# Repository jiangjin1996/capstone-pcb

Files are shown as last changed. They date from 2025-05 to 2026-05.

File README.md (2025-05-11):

# Analog Circuit Reliability for Low Earth Orbit Space Applications

In collaboration with the University of Saskatchewan, we are contributing a payload board
for the CubeSats Initiative in Canada for STEM (CUBICS). A CubeSat is a low cost, small
and approachable design for students “to engage in an end-to-end space mission
adapted to their needs and their level of comfort, expertise and readiness” (asc-csa.
gc.ca). Our payload studies the effects of space radiation on commonly used surface
mount analog Integrated Circuits (IC’s) in Low Earth Orbit (LEO). We compare different
shielding to see which provides a better effectiveness to weight ratio.

poster

## Software

Available [here](https://github.com/kaitallaoua/capstone-cubeide)

## Setup

This project used KiCad `Version: 7.0.11-7.0.11~ubuntu22.04.1, release build` and a mix of windows builds.
Download KiCad [here](https://www.kicad.org/download/). KiCad 8 likely does work and I recommend you use it.

## Workflow

TBD (remove this once done): Someone needs to fork this repo to make further contributions to the project. Using an organization is best, I think UofS space team has one, maybe Regina team should make one? Regardless I will not be reviewing and accepting PR's to this repo.

Because using git for KiCad is like tracking binary files, I recommend to NOT rely on git handling merge conflicts. Avoid them entirely by letting only one person make changes on one branch at a time, make a PR, approve and merge and repeat and pass the baton to someone else to make changes.

## TODO

- Get I2C working (unlikely any KiCad changes)
- Get sinewave generation working 
- Add Voltage regulator
- Triple check we fit in PC104, on RADSAT-SK1 printout we dont fit in all holes, also supposed to be some notches?
- Optional: Use solder-attched external non volatile storage such as FLASH, EEPROM (or solder/glue micro sd down??)

The most substantial changes the sinwave generation. This task was assigned to Evan. Ultimately we could not get it working, thus I recommend to use a PWM wave gen from the mcu, likely add pre-amplification + current buffering, and pass it to a sharp drop off filter. The filter could be a dedicated one (probably better) or an op-amp driven one (butterworth?, wont have as good drop off without many stages).

UofRobotics is also making a PCB for their robot whose base is forked from this project, they may be a good reference for questions or idea sharing.

## Manufacturing

We used JLCPCB for `REV A` and `REV B` with great results. We also have nearly all parts ready for another revision. AT LEAST ONE MORE REVISION IS NEEDED SINCE THE FOLLOWING WERE FIXED AFTER `REV B`:

- IC1 footprint solder mask was incorrectly removed
- Micro SD card holder was facing the wrong way

Our manufacturing procedure was as follows:

Order from JLC (1 week delivery), Order from Mouser/Digikey (2-4 day delivery) -> Have all parts -> Go to ED435, use microscope, have one person assist finding parts, one pick+place, apply solder paste (min 4-5 hours)-> place in oven -> done

I recommend to use the parts list available from JLCPCB or PCBWay to assemble as much of the board for you as possible, it saves alot of time but honestly building it by hand it also not that bad. Either is fine.

JLC ordering tips:
1. Search for JLC production toolkit to generate the BOM, part placement file.
2. Generate the gerber files with time stamps in the folder name to avoid confusion (only gerber is a really bad name)
3. and do not forget to generate the drill file and put it into the gerber folder(you don't need the toolkit for this)
4. You can hand pick components on JLC if the system cannot find them automatically
5. Double check the 3d model pops up after the components are selected because sometimes the auto selected parts can be the wrong ones
6. Ask for boarding cleaning on the first page of ordering
7. Select add paste for unpopulated pad & step stencil opening for easier installation in case JLC doesn't have the components? (Not sure about this but we will see)
8. These might apply to other manufacturers as well

## Resources

[KiCad 6 STM32 PCB Design Full Tutorial - Phil's Lab #65](https://www.youtube.com/watch?v=aVUqaB0IMh4)

[PCB Design Final Touches (Tips & Checklist) - Phil's Lab #131](https://www.youtube.com/watch?v=g4m91gv-4oQ)

## Front PCB

front_pcb

## Back PCB

back_pcb

## Front Copper Layer

front_cu

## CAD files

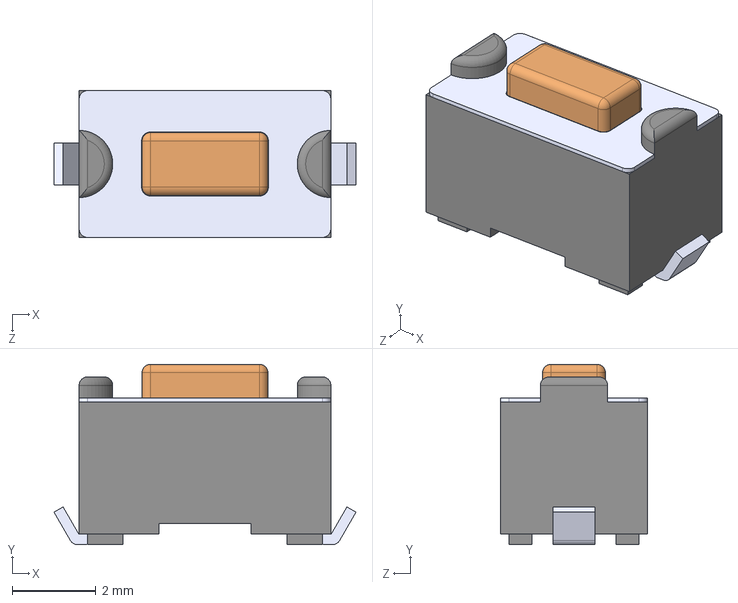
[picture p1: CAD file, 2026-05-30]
pcb/footprint_3d/95C04A3GWRT.stp
7.20 x 4.30 x 3.50 mm

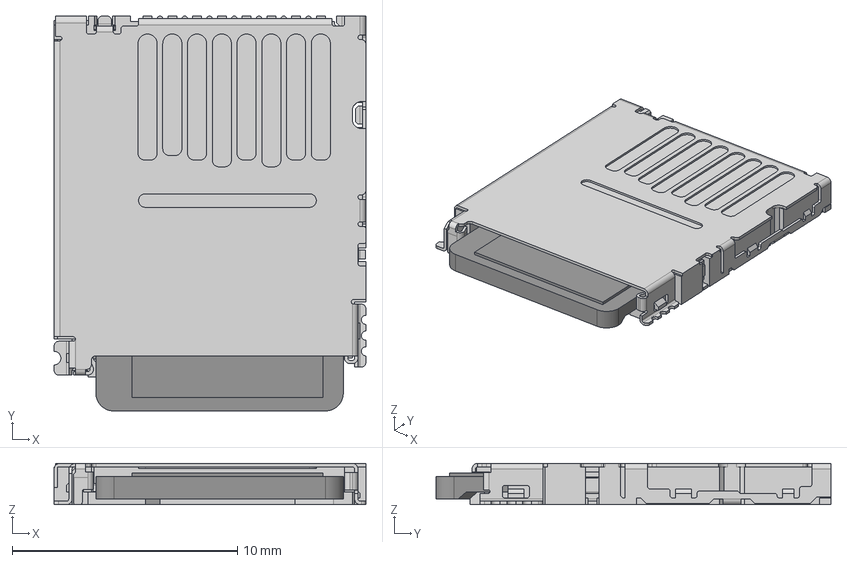
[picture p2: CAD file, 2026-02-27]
pcb/footprint_3d/DM3BT-DSF-PEJS.stp
13.8 x 17.5 x 1.83 mm
CARD_1
DM3BT_1

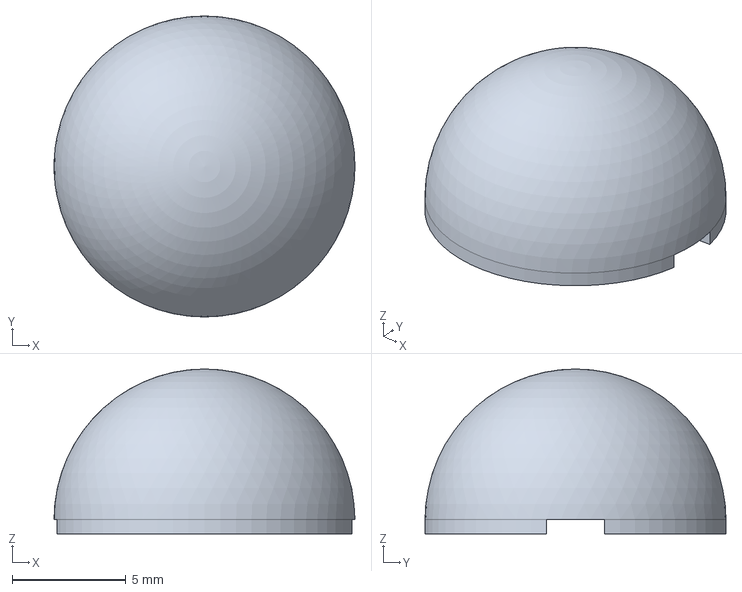
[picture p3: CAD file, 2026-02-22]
pcb/footprint_3d/MelaninShield.stp
13.2 x 13.2 x 7.24 mm

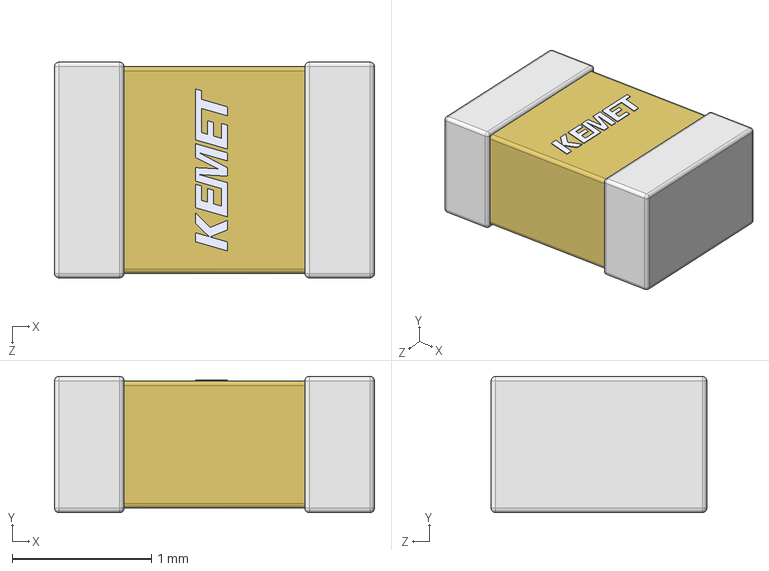
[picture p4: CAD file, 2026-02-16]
pcb/footprint_3d/C0805C224M5VACTU-0.22u.stp
2.30 x 0.98 x 1.55 mm

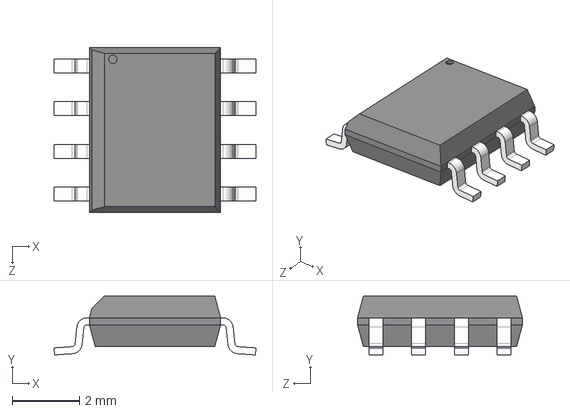
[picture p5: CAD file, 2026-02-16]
pcb/footprint_3d/REF192GSZ.step
6.00 x 1.75 x 4.90 mm

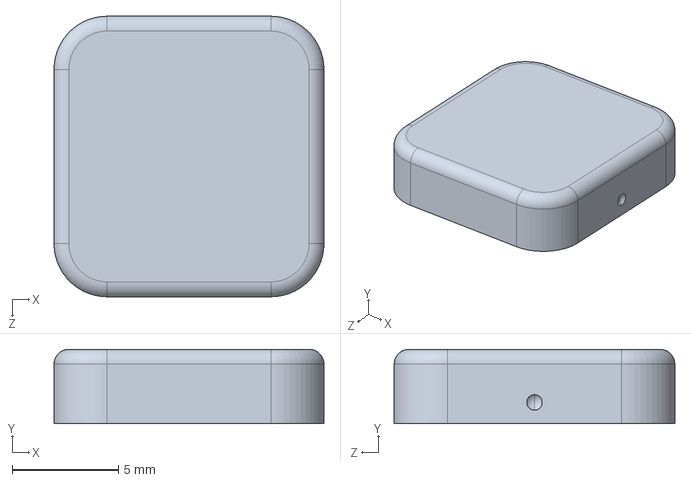
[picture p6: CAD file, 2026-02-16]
pcb/footprint_3d/MS128-10C.step
12.7 x 3.50 x 13.2 mm

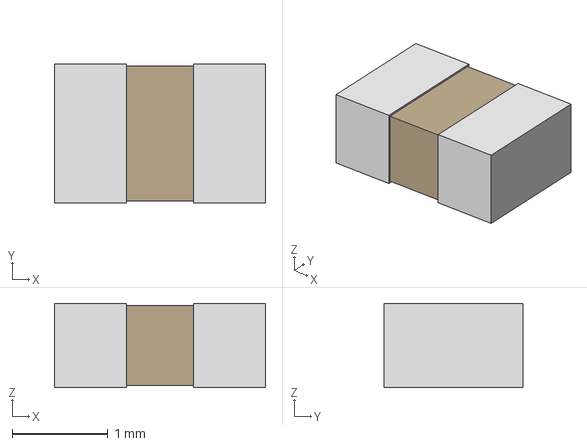
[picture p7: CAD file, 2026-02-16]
pcb/footprint_3d/CAPC220145_88N_KEM.step
2.20 x 1.45 x 0.88 mm

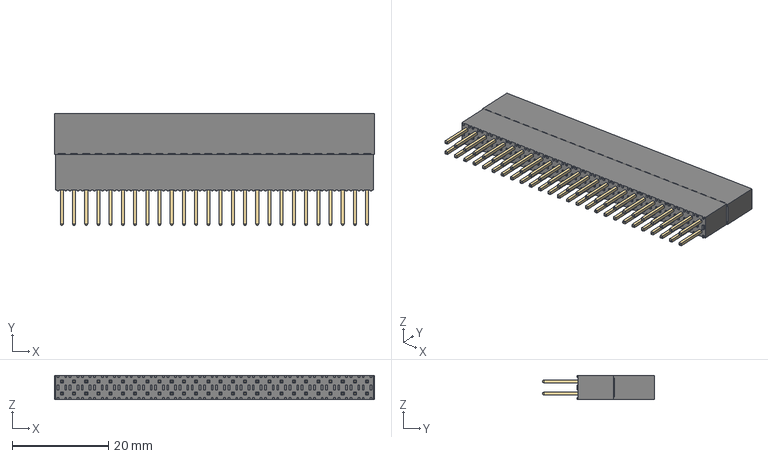
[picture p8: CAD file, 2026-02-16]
pcb/footprint_3d/ESQ-126-39-L-D.stp
66.5 x 23.2 x 5.08 mm

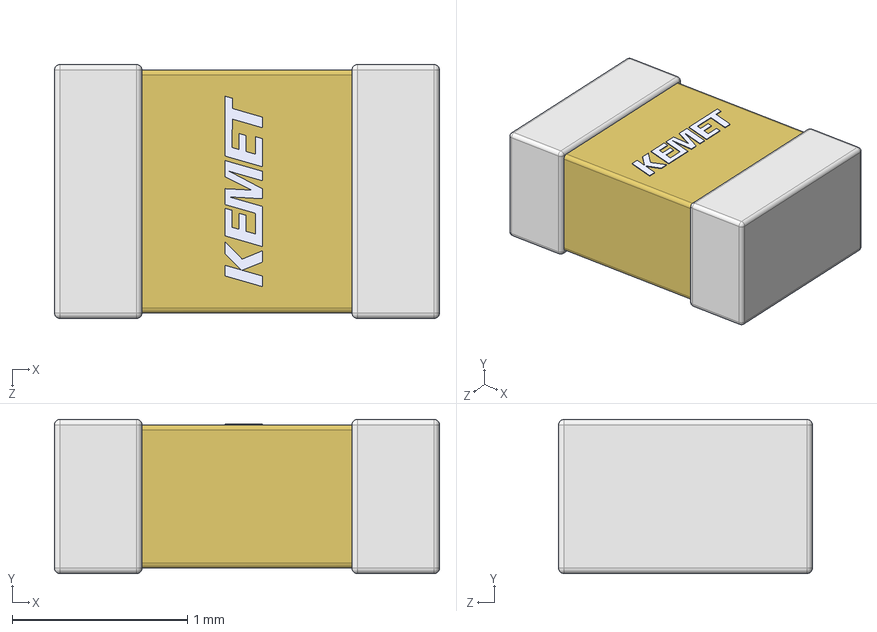
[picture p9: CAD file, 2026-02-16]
pcb/footprint_3d/C0805C103F5GACTU.stp
2.20 x 0.88 x 1.45 mm

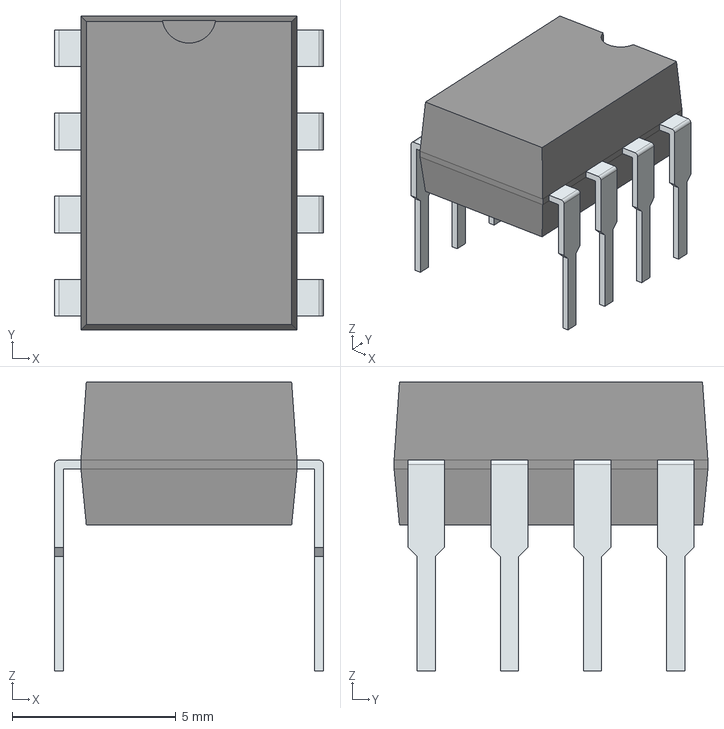
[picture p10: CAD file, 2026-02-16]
pcb/footprint_3d/AD844ANZ.stp
8.22 x 9.59 x 8.83 mm
PinsArrayLR

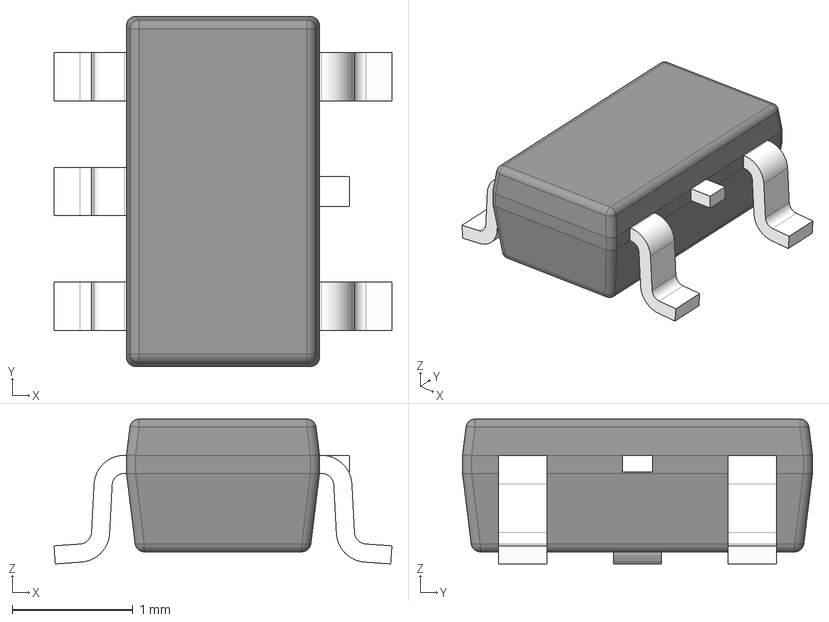
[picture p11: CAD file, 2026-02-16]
pcb/footprint_3d/DBV0005A-MF.stp
2.80 x 2.90 x 1.20 mm
BODY-SOT
LEAD-SOT x 5
LEAD-DUMMY

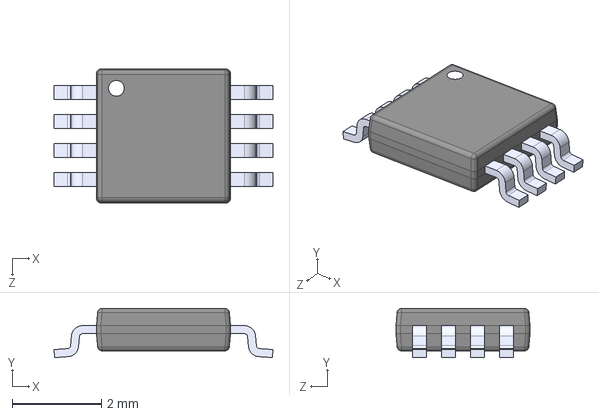
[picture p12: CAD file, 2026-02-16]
pcb/footprint_3d/TL7660IDGKR.step
4.90 x 1.10 x 3.00 mm

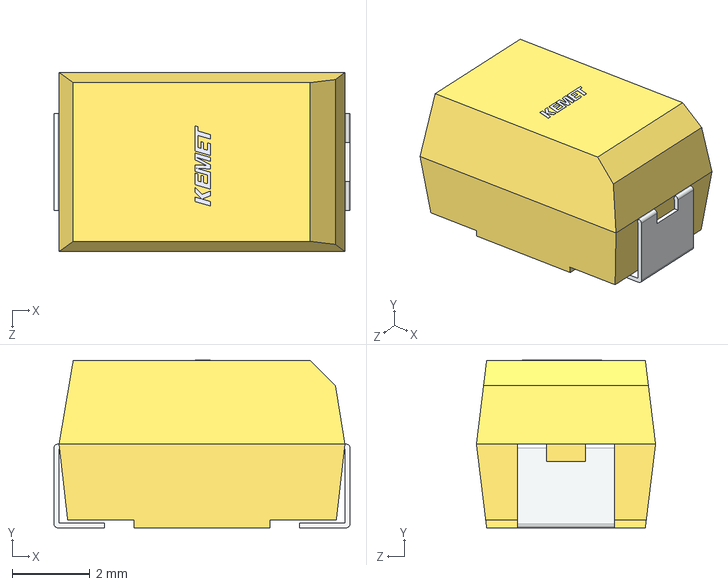
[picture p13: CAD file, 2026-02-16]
pcb/footprint_3d/T495X106K050ATE250-10u.stp
7.60 x 4.31 x 4.60 mm

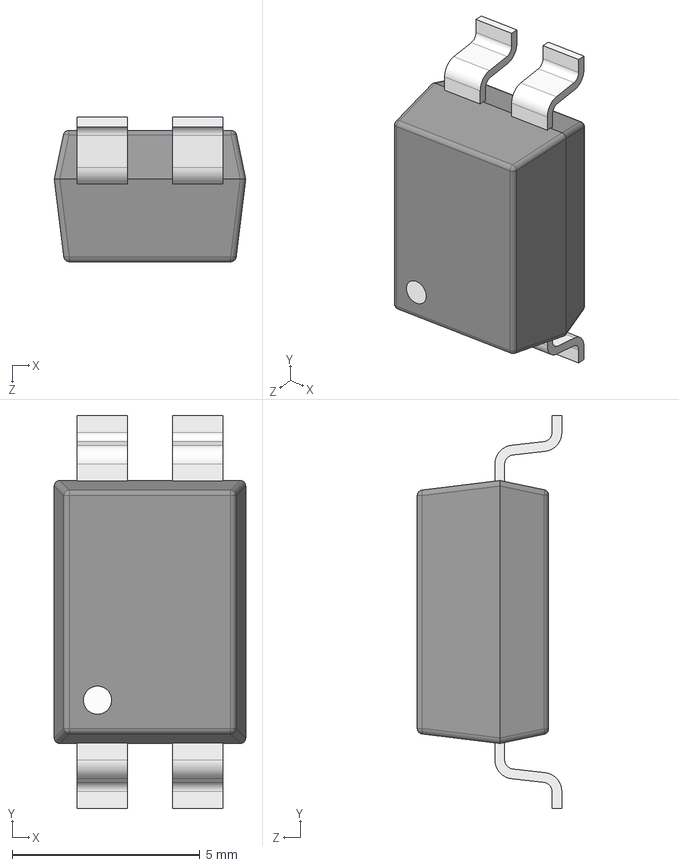
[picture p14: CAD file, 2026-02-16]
pcb/footprint_3d/FOD814SD.stp
5.10 x 10.5 x 3.85 mm

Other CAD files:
pcb/footprint_3d/T495D106K035ATE300.stp
pcb/footprint_3d/TL081IDT.stp
pcb/footprint_3d/ECS-80-18-5PX-GM-TR.stp
pcb/footprint_3d/AD844JRZ_16_REEL7.step
pcb/footprint_3d/C0805C224M5VACTU.step
pcb/footprint_3d/CL32A157MQVNNNE.STEP
pcb/footprint_3d/ESQ-126-39-G-D.stp
pcb/footprint_3d/LM35DM.stp
pcb/footprint_3d/LMT87DCKT.step
pcb/footprint_3d/LTC4300A-1IMS8_PBF.step
pcb/footprint_3d/M22-6003005.stp
pcb/footprint_3d/MS110-20S.step
pcb/footprint_3d/MS168-10S.step
pcb/footprint_3d/MS182-10C-NS.step
pcb/footprint_3d/REF192GSZ_REEL7.step
pcb/footprint_3d/TPS2069CDBVR.step

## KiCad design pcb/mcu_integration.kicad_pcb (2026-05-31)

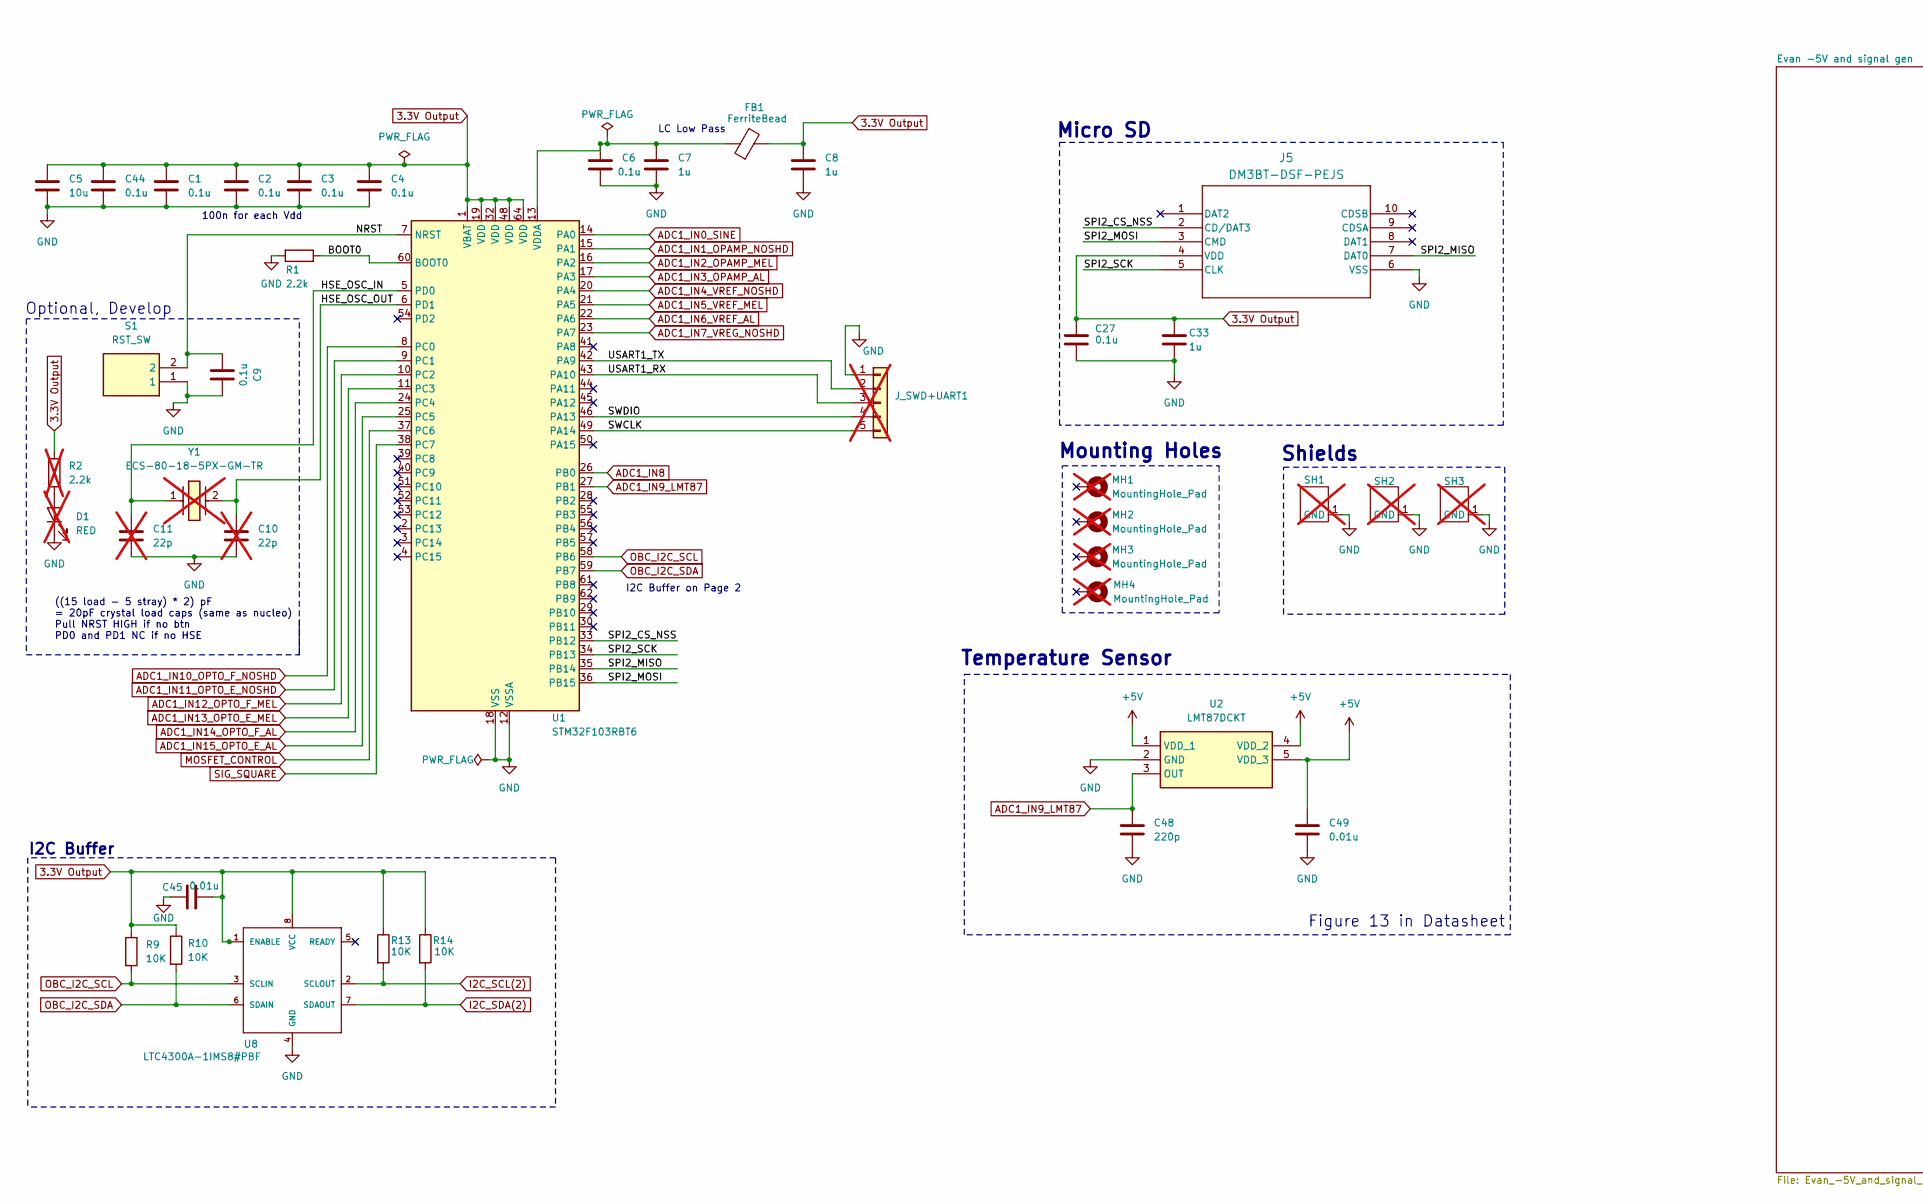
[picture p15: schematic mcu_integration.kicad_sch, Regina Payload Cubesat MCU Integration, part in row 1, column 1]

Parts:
C1, C2, C3, C4, C6, C9, C27, C44: 0.1u; C_0402_1005Metric; MPN C0402C104J4RALTU
C5: 10u; C_0603_1608Metric; MPN C0603C106M9PACTU
C7, C8, C33: 1u; C_0402_1005Metric; MPN 0402ZD105KAT2A
C10, C11: 22p; C_0402_1005Metric; not fitted
C45, C49: 0.01u; C_0402_1005Metric; MPN C0402C103J4RALTU
C48: 220p; C_0402_1005Metric; MPN C0402C221K8RACTU
D1: RED; LED_0603_1608Metric; not fitted
FB1: FerriteBead; L_0603_1608Metric; MPN GZ1608E601TF
J5: DM3BT-DSF-PEJS; DM3BT_DSF_PEJS; MPN DM3BT-DSF-PEJS
J_SWD+UART1: J_SWD+UART1; PinHeader_1x05_P2.54mm_Vertical; not fitted
MH1, MH2, MH3, MH4: MountingHole_Pad; MountingHole_3.18mm_6.35mm_Pad; not fitted
R1: 2.2k; R_0402_1005Metric; MPN CRCW04022K20FKTD
R2: 2.2k; R_0402_1005Metric; MPN CRCW04022K20FKTD; not fitted
R9, R10, R13, R14: 10K; R_0402_1005Metric; MPN CRCW040210K0FKTD
S1: RST_SW; 95C04A3GWRT; Mouser Part Number 706-95C04A3GWRT
SH1: AD844 Shield; not fitted
SH2: FOD814 Shield; not fitted
SH3: REF192 Shield; not fitted
U1: STM32F103RBT6; LQFP-64_10x10mm_P0.5mm; MPN STM32F103RBT6
U2: LMT87DCKT; SOT65P210X110-5N; Mouser Part Number 595-LMT87DCKT
U8: LTC4300A-1IMS8#PBF; LTC4300A-1IMS8_PBF; MPN LTC4300A-1IMS8#PBF
Y1: ECS-80-18-5PX-GM-TR; ECS80185PXGMTR; Mouser Part Number 520-80-18-5PX-GM-TR; not fitted

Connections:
3.3V Output: C1.1, C2.1, C3.1, C4.1, C5.1, C8.1, C27.1, C33.1, C44.1, C45.2, FB1.2, J5.4 (VDD), R2.1, R9.1, R10.1, R13.1, R14.1, U1.1 (VBAT), U1.19 (VDD), U1.32 (VDD), U1.48 (VDD), U1.64 (VDD), U8.1 (ENABLE), U8.8 (VCC); also elsewhere on the board
+5V: C49.1, U2.1 (VDD_1), U2.4 (VDD_2), U2.5 (VDD_3); also elsewhere on the board
/BOOT0: R1.1, U1.60 (BOOT0)
/HSE_OSC_IN: C11.1, U1.5 (PD0), Y1.1
/HSE_OSC_OUT: C10.1, U1.6 (PD1), Y1.2
/NRST: C9.2, S1.2, U1.7 (NRST)
/SPI2_CS_NSS: J5.2 (CD/DAT3), U1.33 (PB12)
/SPI2_MISO: J5.7 (DAT0), U1.35 (PB14)
/SPI2_MOSI: J5.3 (CMD), U1.36 (PB15)
/SPI2_SCK: J5.5 (CLK), U1.34 (PB13)
/SWCLK: J_SWD+UART1.5, U1.49 (PA14)
/SWDIO: J_SWD+UART1.4, U1.46 (PA13)
/USART1_RX: J_SWD+UART1.3, U1.43 (PA10)
/USART1_TX: J_SWD+UART1.2, U1.42 (PA9)
ADC1_IN0_SINE: U1.14 (PA0); also elsewhere on the board
ADC1_IN1_OPAMP_NOSHD: U1.15 (PA1); also elsewhere on the board
ADC1_IN2_OPAMP_MEL: U1.16 (PA2); also elsewhere on the board
ADC1_IN3_OPAMP_AL: U1.17 (PA3); also elsewhere on the board
ADC1_IN4_VREF_NOSHD: U1.20 (PA4); also elsewhere on the board
ADC1_IN5_VREF_MEL: U1.21 (PA5); also elsewhere on the board
ADC1_IN6_VREF_AL: U1.22 (PA6); also elsewhere on the board
ADC1_IN7_VREG_NOSHD: U1.23 (PA7)
ADC1_IN8: U1.26 (PB0)
ADC1_IN9_LMT87: C48.1, U1.27 (PB1), U2.3 (OUT); also elsewhere on the board
ADC1_IN10_OPTO_F_NOSHD: U1.8 (PC0); also elsewhere on the board
ADC1_IN11_OPTO_E_NOSHD: U1.9 (PC1); also elsewhere on the board
ADC1_IN12_OPTO_F_MEL: U1.10 (PC2); also elsewhere on the board
ADC1_IN13_OPTO_E_MEL: U1.11 (PC3); also elsewhere on the board
ADC1_IN14_OPTO_F_AL: U1.24 (PC4); also elsewhere on the board
ADC1_IN15_OPTO_E_AL: U1.25 (PC5); also elsewhere on the board
GND: C1.2, C2.2, C3.2, C4.2, C5.2, C6.2, C7.2, C8.2, C9.1, C10.2, C11.2, C27.2, C33.2, C44.2, C45.1, C48.2, C49.2, D1.1 (K), J5.6 (VSS), J_SWD+UART1.1, R1.2, S1.1, SH1.1 (GND_1), SH2.1 (GND_1), SH3.1 (GND_1), U1.12 (VSSA), U1.18 (VSS), U1.31 (VSS), U1.47 (VSS), U1.63 (VSS), U2.2 (GND), U8.4 (GND); also elsewhere on the board
I2C_SCL(2): R13.2, U8.2 (SCLOUT); also elsewhere on the board
I2C_SDA(2): R14.2, U8.7 (SDAOUT); also elsewhere on the board
MOSFET_CONTROL: U1.37 (PC6); also elsewhere on the board
unnamed: C6.1, C7.1, FB1.1, U1.13 (VDDA)
OBC_I2C_SCL: R9.2, U1.58 (PB6), U8.3 (SCLIN)
OBC_I2C_SDA: R10.2, U1.59 (PB7), U8.6 (SDAIN)
SIG_SQUARE: U1.38 (PC7); also elsewhere on the board

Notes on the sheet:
((15 load - 5 stray) * 2) pF = 20pF crystal load caps (same as nucleo) Pull NRST HIGH if no btn PD0 and PD1 NC if no HSE
Mounting Holes
Micro SD
Optional, Develop
Shields
I2C Buffer on Page 2
Temperature Sensor
100n for each Vdd
Figure 13 in Datasheet
LC Low Pass
I2C Buffer

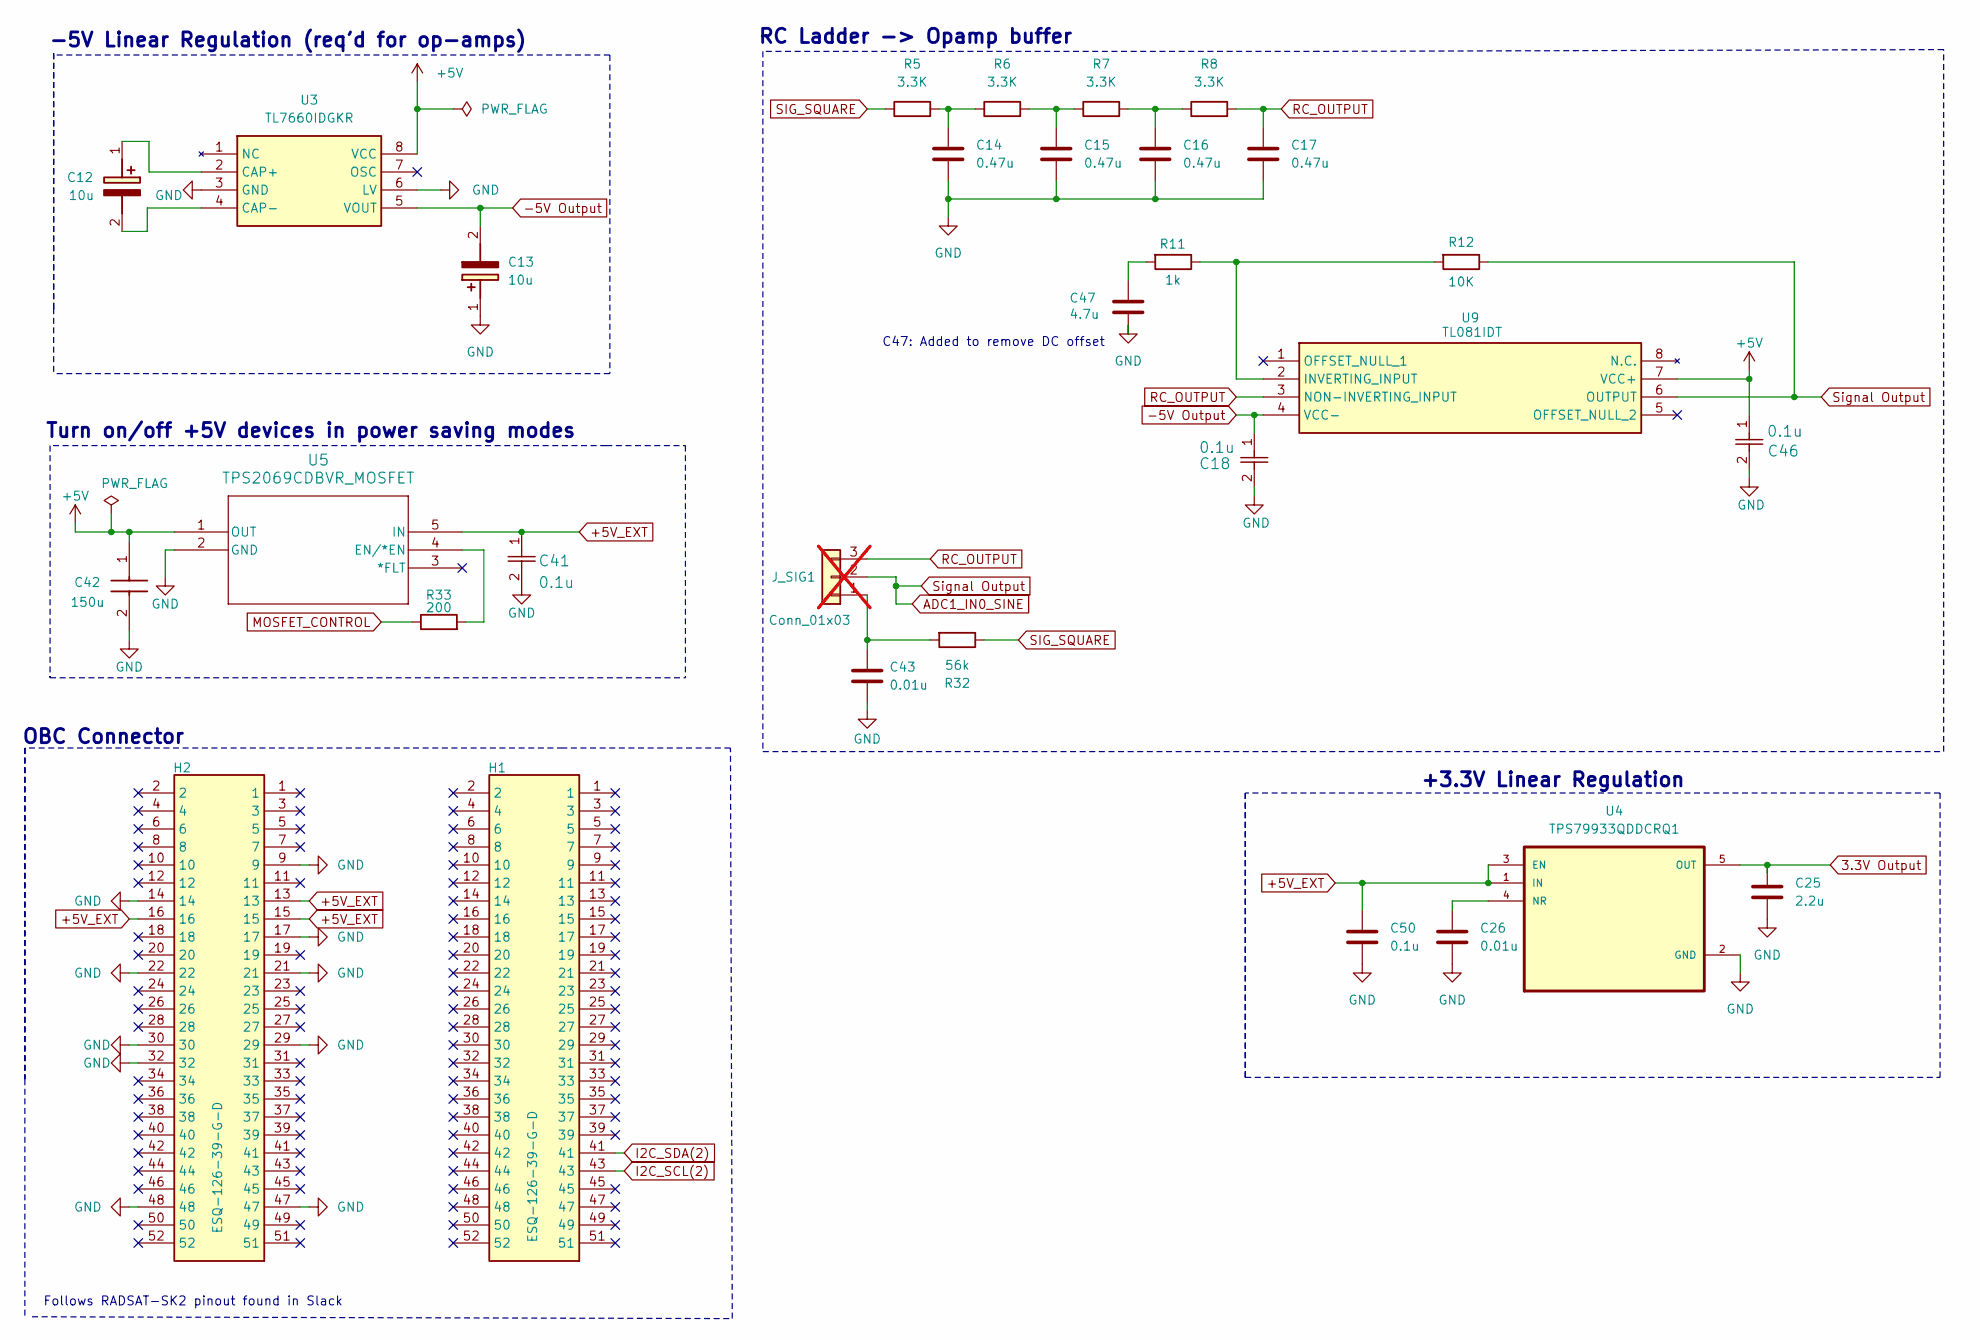
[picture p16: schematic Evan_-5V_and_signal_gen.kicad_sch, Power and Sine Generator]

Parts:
C12, C13: 10u; C_0805_2012Metric; Mouser Part Number 80-T495D106K035
C14, C15, C16, C17: 0.47u; C_0402_1005Metric; MPN KGM05AR51A474KH
C18, C41, C46: 0.1u; C_0805_2012Metric; MPN C0805C104J4RALTU
C25: 2.2u; C_0603_1608Metric; MPN C0603C225K8RACTU
C26, C43: 0.01u; C_0402_1005Metric; MPN C0402C103J4RALTU
C42: 150u; CAPC3225X280N_150U; Mouser Part Number 187-CL32A157MQVNNNE
C47: 4.7u; C_0805_2012Metric; MPN C0805C475J4RACTU
C50: 0.1u; C_0402_1005Metric; MPN C0402C104J4RALTU
H1, H2: ESQ-126-39-G-D; RHDR52W64P254_2X26_6654X495X1135P; Mouser Part Number 200-ESQ12639LD
J_SIG1: Conn_01x03; PinHeader_1x03_P2.54mm_Vertical; not fitted
R5, R6, R7, R8: 3.3K; R_0402_1005Metric; MPN CRCW04023K30FKTD
R11: 1k; R_0402_1005Metric; MPN CRCW04021K00FKTD
R12: 10K; R_0402_1005Metric; MPN CRCW040210K0FKTD
R32: 56k; R_0402_1005Metric; MPN CRCW040256K0FKTD
R33: 200; R_0402_1005Metric; MPN CRCW0402200RFKTD
U3: TL7660IDGKR; SOP65P490X110-8N-actual; Mouser Part Number 595-TL7660IDGKR
U4: TPS79933QDDCRQ1; SOT95P280X110-5N; MPN TPS79933QDDCRQ1
U5: TPS2069CDBVR_MOSFET; DBV5_TEX_MF; MPN TPS2069CDBVR
U9: TL081IDT; SOIC127P600X175-8N; Mouser Part Number 511-TL081IDT

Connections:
3.3V Output: C25.1, U4.5 (OUT); also elsewhere on the board
+5V: C42.1, C46.1, U3.8 (VCC), U5.1 (OUT), U9.7 (VCC+); also elsewhere on the board
+5V_EXT: C41.1, C50.1, H2.13, H2.15, H2.16, U4.1 (IN), U4.3 (EN), U5.5 (IN)
-5V Output: C13.2 (-), C18.1, U3.5 (VOUT), U9.4 (VCC-); also elsewhere on the board
ADC1_IN0_SINE: J_SIG1.2, R12.1, U9.6 (OUTPUT); also elsewhere on the board
GND: C13.1 (+), C14.2, C15.2, C16.2, C17.2, C18.2, C25.2, C26.2, C41.2, C42.2, C43.1, C46.2, C47.2, C50.2, H2.9, H2.14, H2.17, H2.21, H2.22, H2.29, H2.30, H2.32, H2.47, H2.48, U3.3 (GND), U3.6 (LV), U4.2 (GND), U5.2 (GND); also elsewhere on the board
I2C_SCL(2): H1.43; also elsewhere on the board
I2C_SDA(2): H1.41; also elsewhere on the board
MOSFET_CONTROL: R33.1; also elsewhere on the board
unnamed: C12.1 (+), U3.2 (CAP+)
unnamed: C12.2 (-), U3.4 (CAP-)
unnamed: C14.1, R5.2, R6.1
unnamed: C15.1, R6.2, R7.1
unnamed: C16.1, R7.2, R8.1
unnamed: C47.1, R11.2
unnamed: C43.2, J_SIG1.1, R32.2
unnamed: C26.1, U4.4 (NR)
unnamed: R33.2, U5.4 (EN/*EN)
unnamed: R11.1, R12.2, U9.2 (INVERTING_INPUT)
RC_OUTPUT: C17.1, J_SIG1.3, R8.2, U9.3 (NON-INVERTING_INPUT)
SIG_SQUARE: R5.1, R32.1; also elsewhere on the board

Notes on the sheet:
OBC Connector
+3.3V Linear Regulation
-5V Linear Regulation (req'd for op-amps)
RC Ladder -> Opamp buffer
Turn on/off +5V devices in power saving modes
Follows RADSAT-SK2 pinout found in Slack
C47: Added to remove DC offset

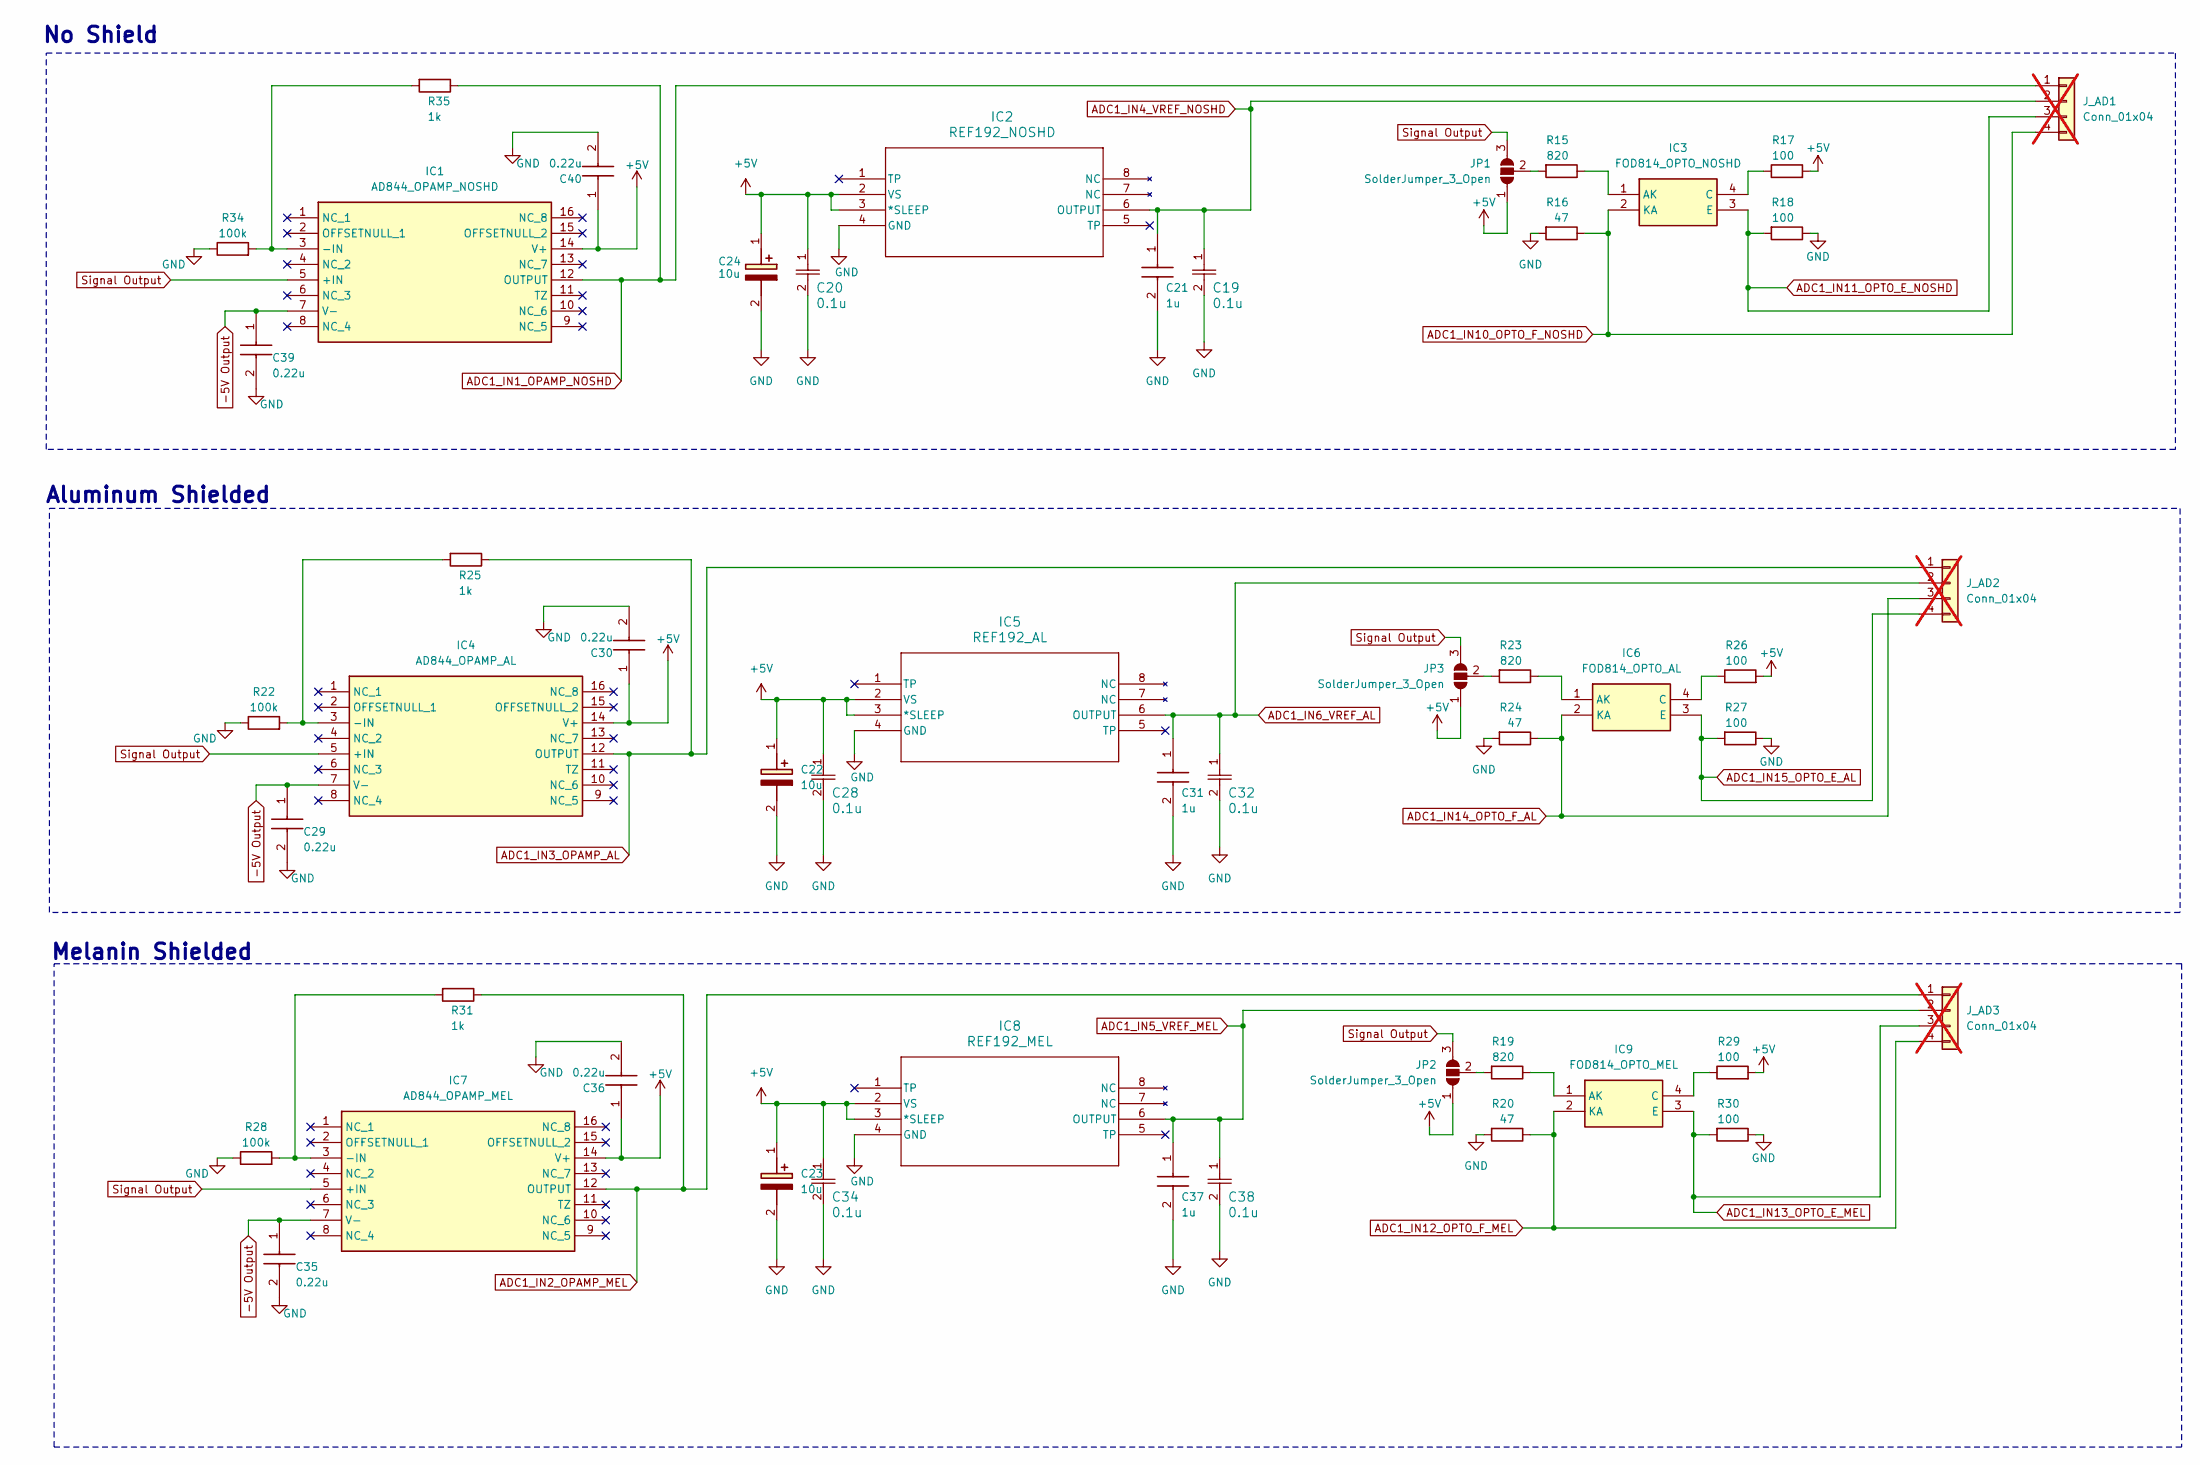
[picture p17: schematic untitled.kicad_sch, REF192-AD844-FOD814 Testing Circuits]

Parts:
C19, C20, C28, C32, C34, C38: 0.1u; C_0805_2012Metric; MPN C0805C104J4RALTU
C21, C31, C37: 1u; C0805-1u; Mouser Part Number 80-C0805C105Z5VACTU
C22, C23, C24: 10u; C_0805_2012Metric; Mouser Part Number 80-T495D106K035
C29, C30, C35, C36, C39, C40: 0.22u; C0805-0.22u; MPN C0805C224J4RALTU
IC1: AD844_OPAMP_NOSHD; SOIC127P1032X265-16N-AD844; Mouser Part Number 584-AD844JRZ-16-R7
IC2: REF192_NOSHD; R_8_ADI-REF; MPN REF192GSZ
IC3: FOD814_OPTO_NOSHD; SOP254P1016X385-4N-FOD; Mouser Part Number 512-FOD814SD
IC4: AD844_OPAMP_AL; SOIC127P1032X265-16N-AD844; Mouser Part Number 584-AD844JRZ-16-R7
IC5: REF192_AL; R_8_ADI-REF; MPN REF192GSZ
IC6: FOD814_OPTO_AL; SOP254P1016X385-4N-FOD; Mouser Part Number 512-FOD814SD
IC7: AD844_OPAMP_MEL; SOIC127P1032X265-16N-AD844; Mouser Part Number 584-AD844JRZ-16-R7
IC8: REF192_MEL; R_8_ADI-REF; MPN REF192GSZ
IC9: FOD814_OPTO_MEL; SOP254P1016X385-4N-FOD; Mouser Part Number 512-FOD814SD
JP1, JP2, JP3: SolderJumper_3_Open; SolderJumper-3_P2.0mm_Open_TrianglePad1.0x1.5mm
J_AD1, J_AD2, J_AD3: Conn_01x04; PinHeader_1x04_P2.54mm_Vertical; not fitted
R15, R19, R23: 820; R_0402_1005Metric; MPN CRCW0402820RFKED
R16, R20, R24: 47; R_0402_1005Metric; MPN CRCW040247R0FKTD
R17, R18, R26, R27, R29, R30: 100; R_0402_1005Metric; MPN CRCW0402100RFKTD
R22, R28, R34: 100k; R_0402_1005Metric; MPN CRCW0402100KFKTD
R25, R31, R35: 1k; R_0402_1005Metric; MPN CRCW04021K00FKTD

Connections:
+5V: C20.1, C22.1 (+), C23.1 (+), C24.1 (+), C28.1, C30.1, C34.1, C36.1, C40.1, IC1.14 (V+), IC2.2 (VS), IC2.3 (*SLEEP), IC4.14 (V+), IC5.2 (VS), IC5.3 (*SLEEP), IC7.14 (V+), IC8.2 (VS), IC8.3 (*SLEEP), JP1.1 (A), JP2.1 (A), JP3.1 (A), R17.2, R26.2, R29.2; also elsewhere on the board
-5V Output: C29.1, C35.1, C39.1, IC1.7 (V-), IC4.7 (V-), IC7.7 (V-); also elsewhere on the board
ADC1_IN0_SINE: IC1.5 (+IN), IC4.5 (+IN), IC7.5 (+IN), JP1.3 (B), JP2.3 (B), JP3.3 (B); also elsewhere on the board
ADC1_IN1_OPAMP_NOSHD: IC1.12 (OUTPUT), J_AD1.1, R35.1; also elsewhere on the board
ADC1_IN2_OPAMP_MEL: IC7.12 (OUTPUT), J_AD3.1, R31.1; also elsewhere on the board
ADC1_IN3_OPAMP_AL: IC4.12 (OUTPUT), J_AD2.1, R25.1; also elsewhere on the board
ADC1_IN4_VREF_NOSHD: C19.1, C21.1, IC2.6 (OUTPUT), J_AD1.2; also elsewhere on the board
ADC1_IN5_VREF_MEL: C37.1, C38.1, IC8.6 (OUTPUT), J_AD3.2; also elsewhere on the board
ADC1_IN6_VREF_AL: C31.1, C32.1, IC5.6 (OUTPUT), J_AD2.2; also elsewhere on the board
ADC1_IN10_OPTO_F_NOSHD: IC3.2 (KA), J_AD1.4, R16.1; also elsewhere on the board
ADC1_IN11_OPTO_E_NOSHD: IC3.3 (E), J_AD1.3, R18.2; also elsewhere on the board
ADC1_IN12_OPTO_F_MEL: IC9.2 (KA), J_AD3.4, R20.1; also elsewhere on the board
ADC1_IN13_OPTO_E_MEL: IC9.3 (E), J_AD3.3, R30.2; also elsewhere on the board
ADC1_IN14_OPTO_F_AL: IC6.2 (KA), J_AD2.3, R24.1; also elsewhere on the board
ADC1_IN15_OPTO_E_AL: IC6.3 (E), J_AD2.4, R27.2; also elsewhere on the board
GND: C19.2, C20.2, C21.2, C22.2 (-), C23.2 (-), C24.2 (-), C28.2, C29.2, C30.2, C31.2, C32.2, C34.2, C35.2, C36.2, C37.2, C38.2, C39.2, C40.2, IC2.4 (GND), IC5.4 (GND), IC8.4 (GND), R16.2, R18.1, R20.2, R22.1, R24.2, R27.1, R28.1, R30.1, R34.1; also elsewhere on the board
unnamed: IC1.3 (-IN), R34.2, R35.2
unnamed: IC3.1 (AK), R15.1
unnamed: IC3.4 (C), R17.1
unnamed: IC4.3 (-IN), R22.2, R25.2
unnamed: IC6.1 (AK), R23.1
unnamed: IC6.4 (C), R26.1
unnamed: IC7.3 (-IN), R28.2, R31.2
unnamed: IC9.1 (AK), R19.1
unnamed: IC9.4 (C), R29.1
unnamed: JP1.2 (C), R15.2
unnamed: JP2.2 (C), R19.2
unnamed: JP3.2 (C), R23.2

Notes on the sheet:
Aluminum Shielded
Melanin Shielded
No Shield

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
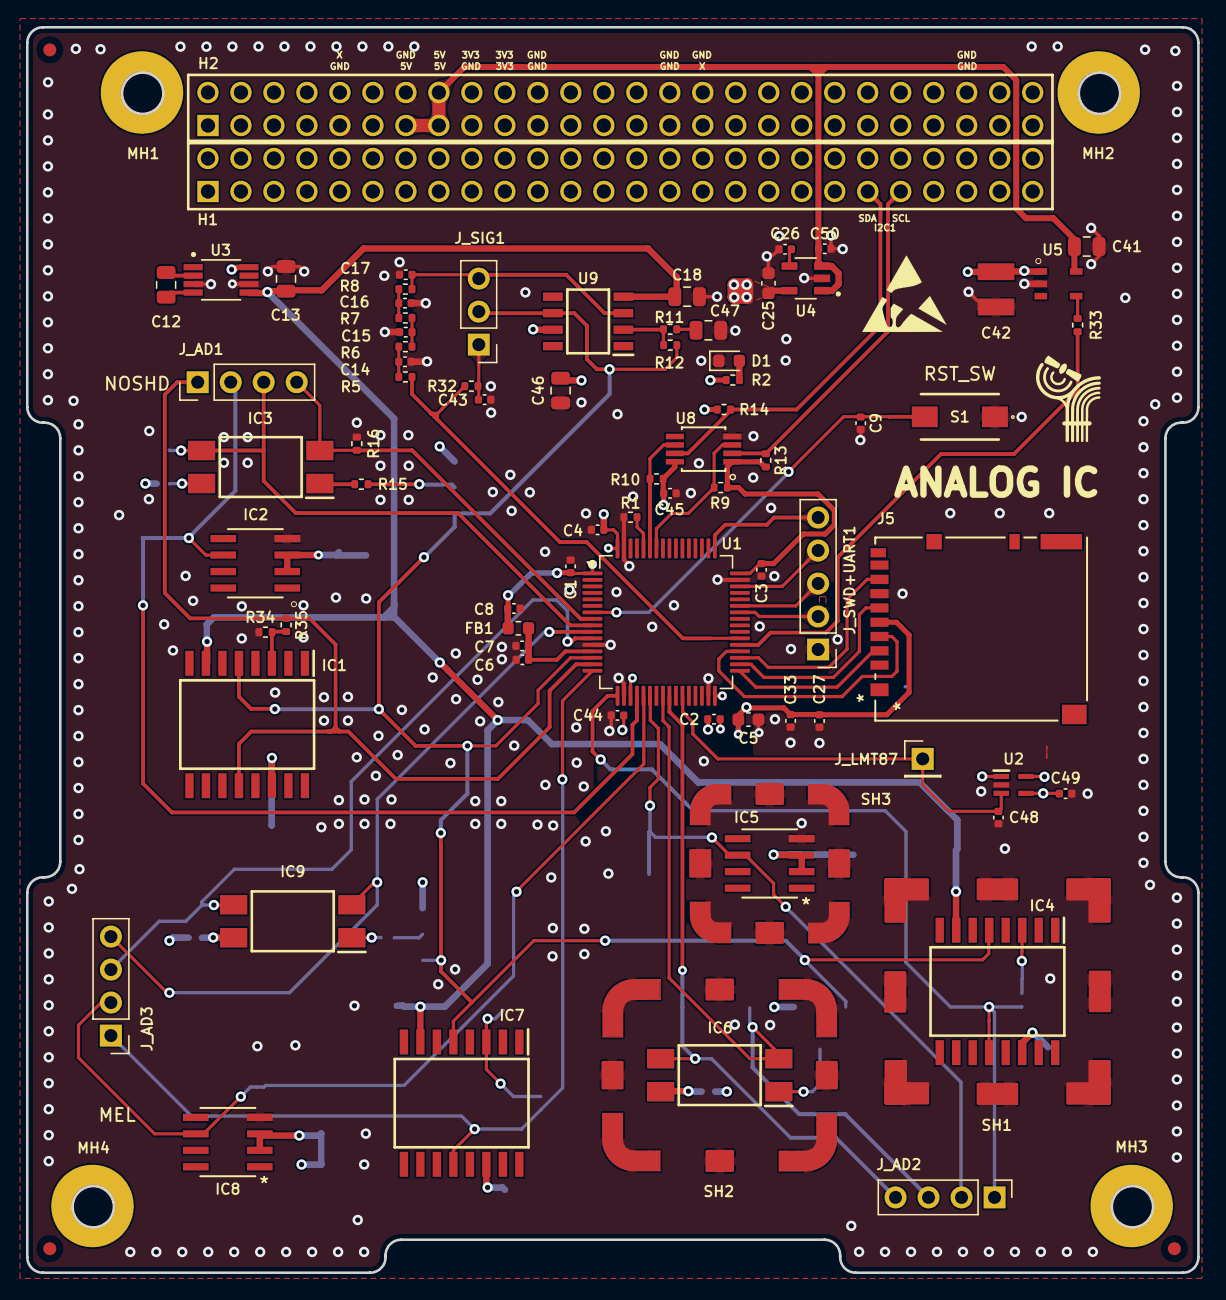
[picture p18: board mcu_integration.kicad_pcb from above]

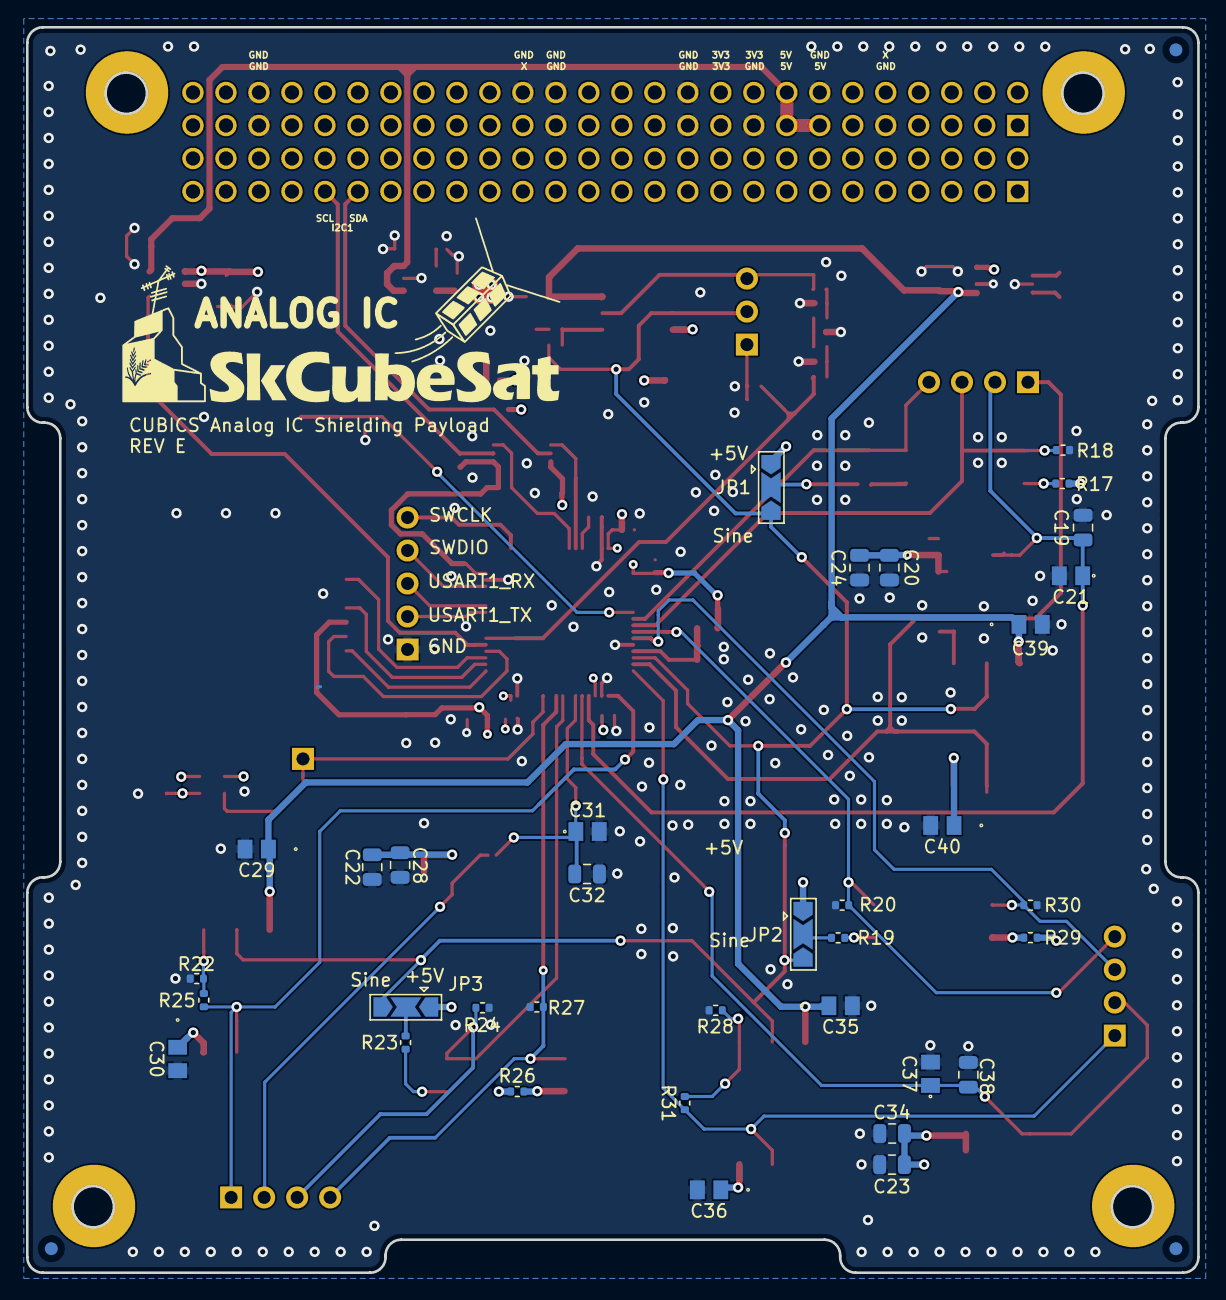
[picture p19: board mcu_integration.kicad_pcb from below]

Board: 4 copper layers, 90.2 x 95.9 mm, 118 parts (35 on the bottom side), 59 nets.

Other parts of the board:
J_LMT87: Conn_01x01; PinHeader_1x01_P2.54mm_Vertical

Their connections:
ADC1_IN9_LMT87: J_LMT87.1; also elsewhere on the board

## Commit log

2024-11-17 Create RAD2-GEN-ICD-001A-Subsystem_External_Connections.xlsx
    CSKB Pin out file
    [RAD2-GEN-ICD-001A-Subsystem_External_Connections.xlsx]
2024-11-24 Working Commit - Nov24
    [Evan_-5V_and_signal_gen.kicad_sch, mcu_integration.kicad_pcb, mcu_integration.kicad_sch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]
2024-12-01 FIxed PCB shape and mounting holes
    [mcu_integration.kicad_pcb]
2024-12-08 SD card change
    [DM3BT_DSF_PEJS.stp, mcu_integration.kicad_pcb, mcu_integration.kicad_sch]
2025-01-26 Routed all connections
    [mcu_integration.kicad_pcb]
2025-02-11 Added LM35 Temp Sensor
    [Evan_-5V_and_signal_gen.kicad_sch, LM35DM.stp, mcu_integration.kicad_pcb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]
2025-02-23 Added GND and PWR planes
    [Evan_-5V_and_signal_gen.kicad_sch, mcu_integration.kicad_pcb, mcu_integration.kicad_sch]
2025-02-23 Connected GND connections to GND plane
    [mcu_integration.kicad_pcb]
2025-03-02 Added +5v connections
    [Evan_-5V_and_signal_gen.kicad_sch, mcu_integration.kicad_pcb, mcu_integration.kicad_sch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]
2025-03-09 Added RC Ladder Circuit
    [Evan_-5V_and_signal_gen.kicad_sch, mcu_integration.kicad_pcb]
2025-03-09 Routed all RC ladder connections
    [Evan_-5V_and_signal_gen.kicad_sch, mcu_integration.kicad_pcb, mcu_integration.kicad_sch]
2025-03-16 Fixed PCB silkscreen
    [mcu_integration.kicad_pcb]
2025-03-26 Added silkscreen and changed diode footprints
    [mcu_integration.kicad_pcb, mcu_integration.kicad_sch]
2025-05-11 Added reset button & LED, fixed SD card overhang
    [Evan_-5V_and_signal_gen.kicad_sch, mcu_integration.kicad_pcb, mcu_integration.kicad_sch]
2025-05-11 Added non-inverting amplifier to RC Ladder and Changed header pin
    [Evan_-5V_and_signal_gen.kicad_sch, mcu_integration.kicad_pcb, mcu_integration.kicad_sch]
2025-05-18 Fixed silkscreen and component values
    [Evan_-5V_and_signal_gen.kicad_sch, mcu_integration.kicad_pcb]
2025-06-09 Updated CSKB connector
    [Evan_-5V_and_signal_gen.kicad_sch, mcu_integration.kicad_pcb]
2025-06-22 Added missing decoupling capacitor + changed capacitors footprint
    [Evan_-5V_and_signal_gen.kicad_sch, mcu_integration.kicad_pcb, mcu_integration.kicad_sch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]
2025-08-10 Added copper pours to top and bottom layer, added 3.3v plane, spaced ICs to fit melanin caps, ungrounded connection pads, added stitching vias to outer edge
    [Evan_-5V_and_signal_gen.kicad_sch, mcu_integration.kicad_pcb, mcu_integration.kicad_sch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]
2025-08-17 Conformed to JLC DFM
    [mcu_integration.kicad_pcb]
2025-08-24 Added Shield Footprints
    [mcu_integration.kicad_pcb, mcu_integration.kicad_sch]
2025-08-31 Adjusted spacing of shields to allow for easier soldering
    [mcu_integration.kicad_pcb]
2025-09-07 Fixed Shield Solder Mask
    [Evan_-5V_and_signal_gen.kicad_sch, mcu_integration.kicad_pcb, mcu_integration.kicad_sch]
2025-09-07 Moved resistors and capacitors to back of board
    [mcu_integration.kicad_pcb]
2025-09-21 Moved control IC capacitors to back of board to conform with other IC groups
    [Evan_-5V_and_signal_gen.kicad_sch, mcu_integration.kicad_pcb]
2025-12-14 Added switchable inputs for opamps
    [AD844JRZ_16_REEL7.step, Evan_-5V_and_signal_gen.kicad_sch, LTC4300A-1IMS8_PBF.step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]
2026-01-04 Moved Shielded ICs
    [mcu_integration.kicad_pcb]
2026-01-11 Changed IC orientation
    [mcu_integration.kicad_pcb, mcu_integration.kicad_sch, untitled.kicad_sch]
2026-01-11 Production files
    [mcu_integration.kicad_pcb]
2026-01-16 Thermal Reliefs and Blind Vias
    - Added back thermal reliefs to shields
    - Swapped power vias to not be drilled across all layers
    [Evan_-5V_and_signal_gen.kicad_sch, mcu_integration.kicad_pcb]
2026-02-02 Replaced LM35 temperature sensor with LMT87
    [mcu_integration.kicad_pcb, mcu_integration.kicad_sch]
2026-02-02 Changed C18, C19, C20, C28, C32, C34, C38, C41, C46, C47 footprints to 0805
    [Evan_-5V_and_signal_gen.kicad_sch, mcu_integration.kicad_pcb, untitled.kicad_sch]
2026-02-08 Replaced blind vias with through vias to comply with jlcpcb
    [mcu_integration.kicad_pcb]
2026-02-15 fixed 3D model file paths and added CSKB pin labels
    [C0805C224M5VACTU.step, CL32A157MQVNNNE.STEP, DM3BT-DSF-PEJS.stp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]
2026-02-15 Started selecting BOM
    [mcu_integration.kicad_sch]
2026-02-15 Added more to the BOM
    [Evan_-5V_and_signal_gen.kicad_sch, mcu_integration.kicad_sch, untitled.kicad_sch]
2026-02-16 Finished BOM and fixed file paths for 3D models
    [AD844ANZ.stp, AD844JRZ_16_REEL7.step, C0805C103F5GACTU.stp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]
2026-02-16 Updated BOM
    [mcu_integration.kicad_pcb]
2026-02-18 renewing files for manufacturing quote
    [mcu_integration.kicad_pcb]
2026-02-22 added 3D models for melanin domes
    [MelaninShield.stp, mcu_integration.kicad_pcb]
2026-02-27 Fixed the SD card STEP file
    [DM3BT-DSF-PEJS.stp, mcu_integration.kicad_pcb]
2026-03-01 Moved SD card to top of board
    [mcu_integration.kicad_pcb]
2026-03-06 updated component labels
    [Evan_-5V_and_signal_gen.kicad_sch, mcu_integration.kicad_pcb, mcu_integration.kicad_sch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]
2026-03-08 Added 3.3V regulator
    [Evan_-5V_and_signal_gen.kicad_sch, mcu_integration.kicad_pcb]
2026-03-09 updated schematic lables
    [Evan_-5V_and_signal_gen.kicad_sch, mcu_integration.kicad_pcb, mcu_integration.kicad_sch]
2026-03-15 Changed spacing of test ICs to allow for larger melanin domes
    [Evan_-5V_and_signal_gen.kicad_sch, mcu_integration.kicad_pcb, mcu_integration.kicad_sch]
2026-03-16 Updated 3D Models
    Added model for 3V3 Linear voltage regulator and rescaled models for melanin shields
    [mcu_integration.kicad_pcb]
2026-03-23 Made some minor routing adjustments
    [mcu_integration.kicad_pcb]
2026-05-02 Made minor changes for routing and decoup caps
    [Evan_-5V_and_signal_gen.kicad_sch, mcu_integration.kicad_pcb, mcu_integration.kicad_sch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]
2026-05-06 Adjusted some things
    [mcu_integration.kicad_pcb]
2026-05-09 Fixed i2c teardrops
    [mcu_integration.kicad_pcb]
2026-05-09 Finished C25 BOM designation
    [Evan_-5V_and_signal_gen.kicad_sch, mcu_integration.kicad_pcb, mcu_integration.kicad_sch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]
2026-05-12 Added Fiducials
    [mcu_integration.kicad_pcb]
2026-05-30 Started fixing the BOM
    [95C04A3GWRT.stp, Evan_-5V_and_signal_gen.kicad_sch, mcu_integration.kicad_pcb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]
2026-05-31 Did more work on the BOM
    [Evan_-5V_and_signal_gen.kicad_sch, mcu_integration.kicad_pcb, mcu_integration.kicad_sch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]
2026-05-31 changed STM32 part back to original
    [mcu_integration.kicad_sch]
2026-05-31 Added ferrite bead
    [Evan_-5V_and_signal_gen.kicad_sch, mcu_integration.kicad_pcb, mcu_integration.kicad_sch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]
